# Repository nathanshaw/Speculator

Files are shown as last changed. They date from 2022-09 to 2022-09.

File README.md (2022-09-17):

# Speculator Hardware

This repo contains the PCB layout and schematic files for the Speculator genus.
Speculator is one of three genera developed for the Acropolis family of soundscape augmentation artefacts. Speculator specialises in non-cochlear soundscape augmentation.

The files were created within EAGLE CAD

The Speculator genus firmware is contained in this repo: https://github.com/nathanshaw/unified_hss_firmware

More information about this project can be found here: https://nathanvillicanashaw.com/archive
The Explorator genus can be found here: https://github.com/nathanshaw/explorator
The Legatus genus can be found here: https://github.com/nathanshaw/legatus

The following PCB designs are included in this repo:
----------------------------------------------------

### Speculator major (large)
    96mm diameter
    1x Teensy 3.2 Microcontroller
    1x power switch
    6x firmware control switches
    10x WS2813 NeoPixel LEDs
    2x VEML 6030 Ambient Light Sensors
    2x onboard 18650 LiPo Batteries
    1x 5v voltage regulator (TODO): https://www.pololu.com/product/2870

### Speculator minor mainboard (small)
    76mm diameter
    1x Teensy 3.2 Microcontroller
    1x power switch
    10x firmware control switches
    4x firmware control potentiometers 
    20x WS2813 NeoPixel LEDs
    1x SHTC3 Temperature and Humidity Sensor
    2x onboard 18500 LiPo Batteries
    1x 5v voltage regulator (TODO): https://www.pololu.com/product/2870

### Speculator minor breakout PCB
    54mm diameter
    10-pin JST connector to mate with mainboard
    1x VEML 6030 Ambient Light Sensors
    1x TDK ICS-43434 MEMs microphone
    10x WS2813 NeoPixel LEDs

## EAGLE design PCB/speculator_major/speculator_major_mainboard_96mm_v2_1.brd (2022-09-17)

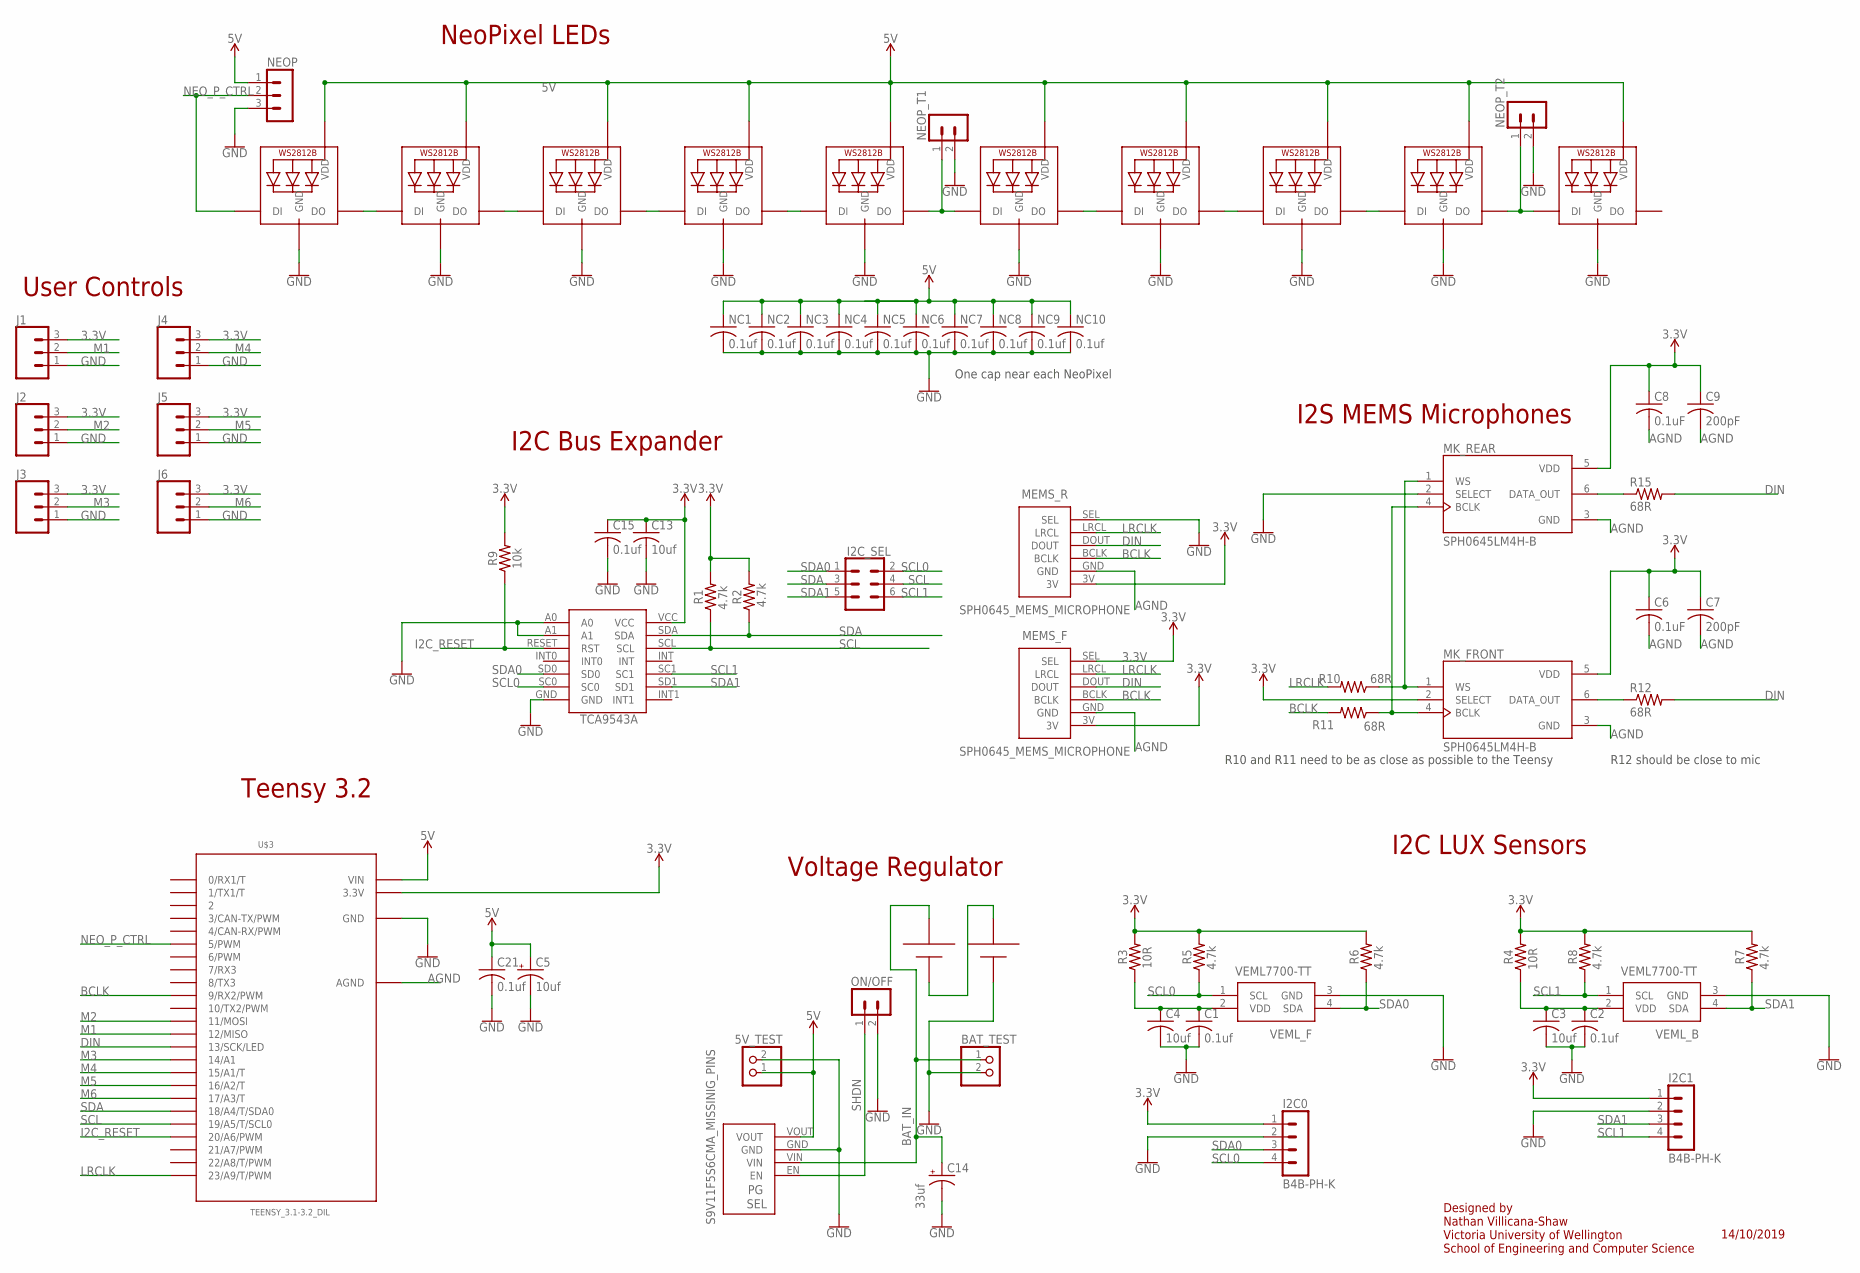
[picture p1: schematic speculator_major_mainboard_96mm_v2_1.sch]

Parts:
5V_TEST: PINHD-1X2; 1X02
BAT_TEST: PINHD-1X2; 1X02
C1, C2, C15, C21: 0.1uf; C1206K
C3, C4, C13: 10uf; C1206K
C5: 10uf; E2,5-6
C6, C8: 0.1uF; C1206K
C7, C9: 200pF; C1206K
C14: 33uf; E2-5
I2C0, I2C1: B4B-PH-K
I2C_SEL: FEMALE 2x3; 2X3
J1, J2, J3, J4, J5, J6: CONN_03; 1X03
MEMS_F: SPH0645_MEMS_MICROPHONE; SPH0645
MEMS_R: SPH0645_MEMS_MICROPHONE; SPH0645
MK_FRONT: SPH0645LM4H-B; MIC_SPH0645LM4H-B
MK_REAR: SPH0645LM4H-B; MIC_SPH0645LM4H-B
NC1, NC2, NC3, NC4, NC5, NC6, NC7, NC8, NC9, NC10: 0.1uf; C1206K
NEO1, NEO2, NEO3, NEO4, NEO5, NEO6, NEO7, NEO8, NEO9, NEO10: WS2812B5050; WS2812B
NEOP: B3B-PH-K
NEOP_T1, NEOP_T2: B2B-PH-K
ON/OFF: B2B-PH-K
R1, R2, R5, R6, R7, R8: 4.7k; R1206W
R3, R4: 10R; R1206W
R9: 10k; R1206W
R10, R11, R12, R15: 68R; M1206
U$1: TCA9543A; SO14
U$2: BK-18650-PC4; 18650-PC4
U$3: TEENSY_3.1-3.2_DIL; TEENSY_3.0-3.2&LC_DIL
U$6: S9V11F5S6CMA_MISSINIG_PINS; S9V11F3S5CMA_MISSING_PINS
VEML_B: VEML7700-TT; VEML7700
VEML_F: VEML7700-TT; VEML7700

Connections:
3.3V: C6.1, C7.1, C8.1, C9.1, C13.1, C15.1, I2C0.1, I2C1.1, J1.3, J2.3, J3.3, J4.3, J5.3, J6.3, MEMS_F.3V, MEMS_F.SEL, MEMS_R.3V, MK_FRONT.2 (SELECT), MK_FRONT.5 (VDD), MK_REAR.5 (VDD), R1.2, R2.2, R3.2, R4.2, R5.2, R6.2, R7.2, R8.2, R9.2, U$1.VCC, U$3.3.3V
5V: 5V_TEST.1, C5.+, C21.1, NC1.1, NC2.1, NC3.1, NC4.1, NC5.1, NC6.1, NC7.1, NC8.1, NC9.1, NC10.1, NEO1.1-VDD (VDD), NEO2.1-VDD (VDD), NEO3.1-VDD (VDD), NEO4.1-VDD (VDD), NEO5.1-VDD (VDD), NEO6.1-VDD (VDD), NEO7.1-VDD (VDD), NEO8.1-VDD (VDD), NEO9.1-VDD (VDD), NEO10.1-VDD (VDD), NEOP.1, U$3.VIN, U$6.VOUT
AGND: C6.2, C7.2, C8.2, C9.2, MEMS_F.GND, MEMS_R.GND, MK_FRONT.3 (GND), MK_REAR.3 (GND), U$3.AGND
BAT_IN: BAT_TEST.1, C14.+, U$2.+1, U$6.VIN
BCLK: MEMS_F.BCLK, MEMS_R.BCLK, R11.2, U$3.9 (9/RX2/PWM)
BCLK_P: MK_FRONT.4 (BCLK), MK_REAR.4 (BCLK), R11.1
DIN: MEMS_F.DOUT, MEMS_R.DOUT, R12.2, R15.2, U$3.13 (13/SCK/LED)
GND: 5V_TEST.2, BAT_TEST.2, C1.2, C2.2, C3.2, C4.2, C5.-, C13.2, C14.-, C15.2, C21.2, I2C0.2, I2C1.2, J1.1, J2.1, J3.1, J4.1, J5.1, J6.1, MEMS_R.SEL, MK_REAR.2 (SELECT), NC1.2, NC2.2, NC3.2, NC4.2, NC5.2, NC6.2, NC7.2, NC8.2, NC9.2, NC10.2, NEO1.3-GND (GND), NEO2.3-GND (GND), NEO3.3-GND (GND), NEO4.3-GND (GND), NEO5.3-GND (GND), NEO6.3-GND (GND), NEO7.3-GND (GND), NEO8.3-GND (GND), NEO9.3-GND (GND), NEO10.3-GND (GND), NEOP.3, NEOP_T1.2, NEOP_T2.2, ON/OFF.2, U$1.A0, U$1.A1, U$1.GND, U$2.-2, U$3.GND, U$6.GND, VEML_B.3 (GND), VEML_F.3 (GND)
I2C_RESET: R9.1, U$1.RESET (RST), U$3.20/A6 (20/A6/PWM)
LRCLK: MEMS_F.LRCL, MEMS_R.LRCL, R10.2, U$3.23/A9 (23/A9/T/PWM)
LRCLK_P: MK_FRONT.1 (WS), MK_REAR.1 (WS), R10.1
M1: J1.2, U$3.12 (12/MISO)
M2: J2.2, U$3.11 (11/MOSI)
M3: J3.2, U$3.14/A0 (14/A1)
M4: J4.2, U$3.15/A1 (15/A1/T)
M5: J5.2, U$3.16/A2 (16/A2/T)
M6: J6.2, U$3.17/A3 (17/A3/T)
unnamed: C1.1, C4.1, R3.1, VEML_F.2 (VDD)
unnamed: C2.1, C3.1, R4.1, VEML_B.2 (VDD)
unnamed: MK_FRONT.6 (DATA_OUT), R12.1
unnamed: NEO2.2-DOUT (DO), NEO3.4-DIN (DI)
unnamed: NEO5.2-DOUT (DO), NEO6.4-DIN (DI), NEOP_T1.1
unnamed: NEO9.2-DOUT (DO), NEO10.4-DIN (DI), NEOP_T2.1
unnamed: NEO4.2-DOUT (DO), NEO5.4-DIN (DI)
unnamed: NEO3.2-DOUT (DO), NEO4.4-DIN (DI)
unnamed: NEO7.2-DOUT (DO), NEO8.4-DIN (DI)
unnamed: NEO8.2-DOUT (DO), NEO9.4-DIN (DI)
unnamed: MK_REAR.6 (DATA_OUT), R15.1
unnamed: U$2.+2, U$2.-1
unnamed: NEO6.2-DOUT (DO), NEO7.4-DIN (DI)
NEO_P1: NEO1.2-DOUT (DO), NEO2.4-DIN (DI)
NEO_P_CTRL: NEO1.4-DIN (DI), NEOP.2, U$3.5 (5/PWM)
SCL: I2C_SEL.4, R1.1, U$1.SCL, U$3.19/A5 (19/A5/T/SCL0)
SCL0: I2C0.4, I2C_SEL.2, R5.1, U$1.SC0, VEML_F.1 (SCL)
SCL1: I2C1.4, I2C_SEL.6, R8.1, U$1.SC1, VEML_B.1 (SCL)
SDA: I2C_SEL.3, R2.1, U$1.SDA, U$3.18/A4 (18/A4/T/SDA0)
SDA0: I2C0.3, I2C_SEL.1, R6.1, U$1.SD0, VEML_F.4 (SDA)
SDA1: I2C1.3, I2C_SEL.5, R7.1, U$1.SD1, VEML_B.4 (SDA)
SHDN: ON/OFF.1, U$6.EN

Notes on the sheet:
I2S MEMS Microphones
Voltage Regulator
I2C LUX Sensors
I2C Bus Expander
NeoPixel LEDs
10k
4.7k
One cap near each NeoPixel
R10 and R11 need to be as close as possible to the Teensy
R12 should be close to mic
10R
Teensy 3.2
Designed by Nathan Villicana-Shaw Victoria University of Wellington School of Engineering and Computer Science
14/10/2019
User Controls

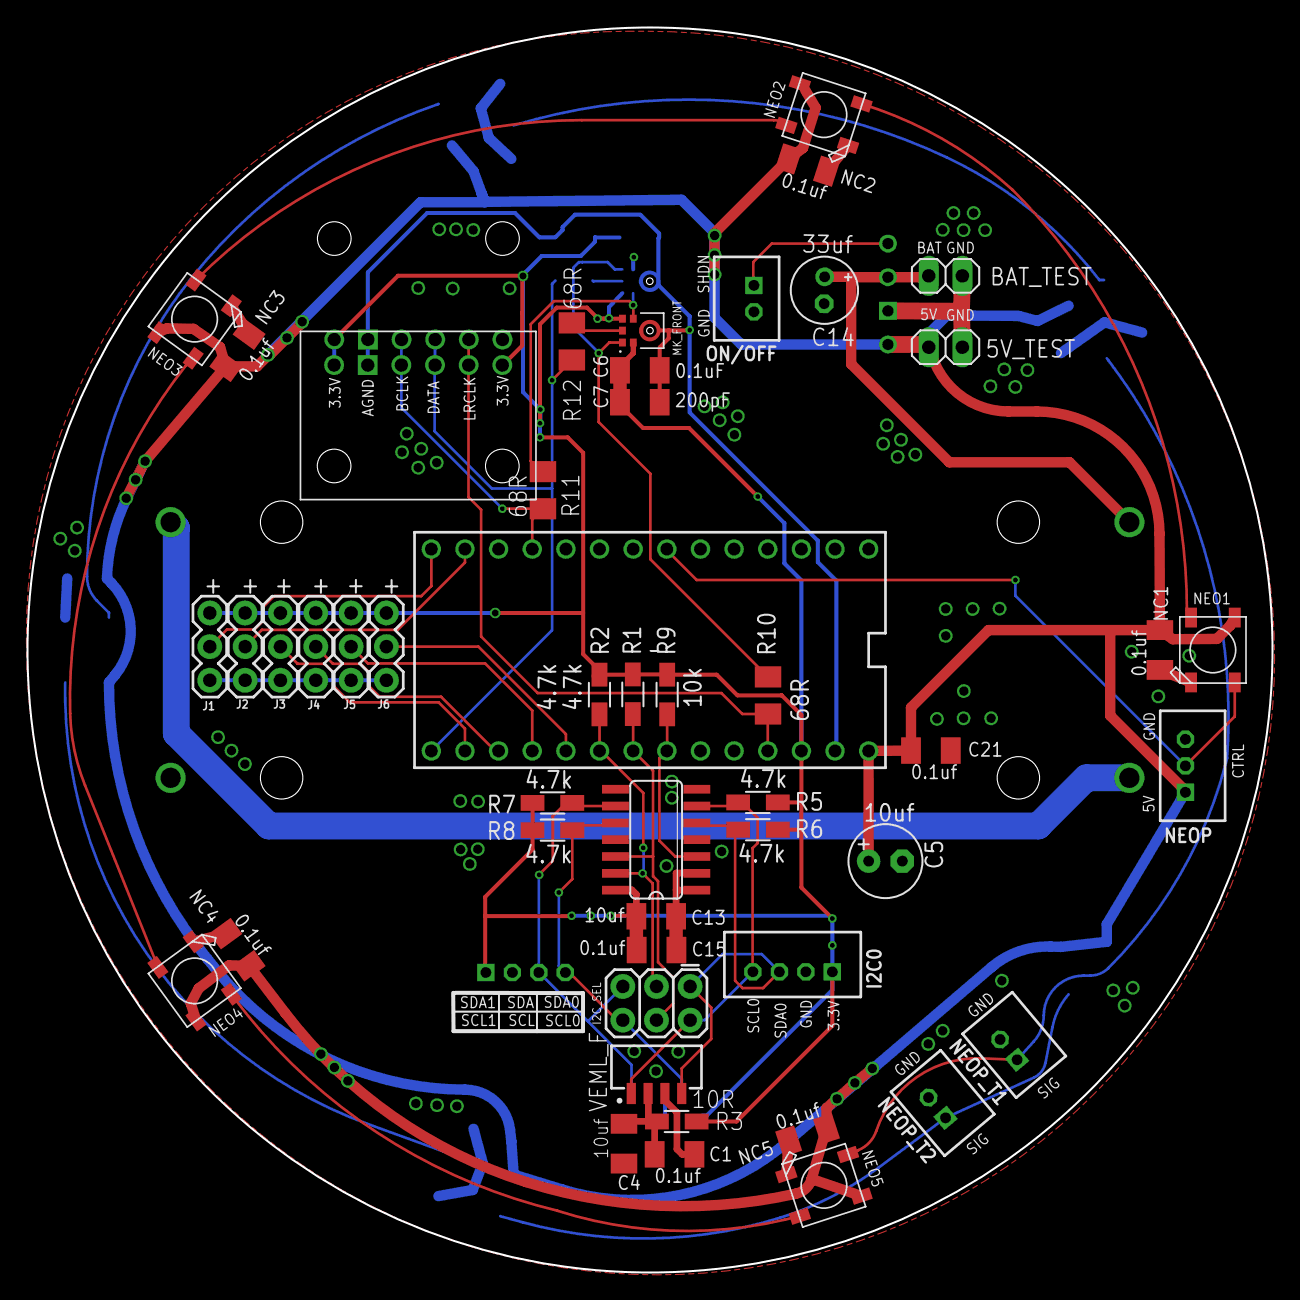
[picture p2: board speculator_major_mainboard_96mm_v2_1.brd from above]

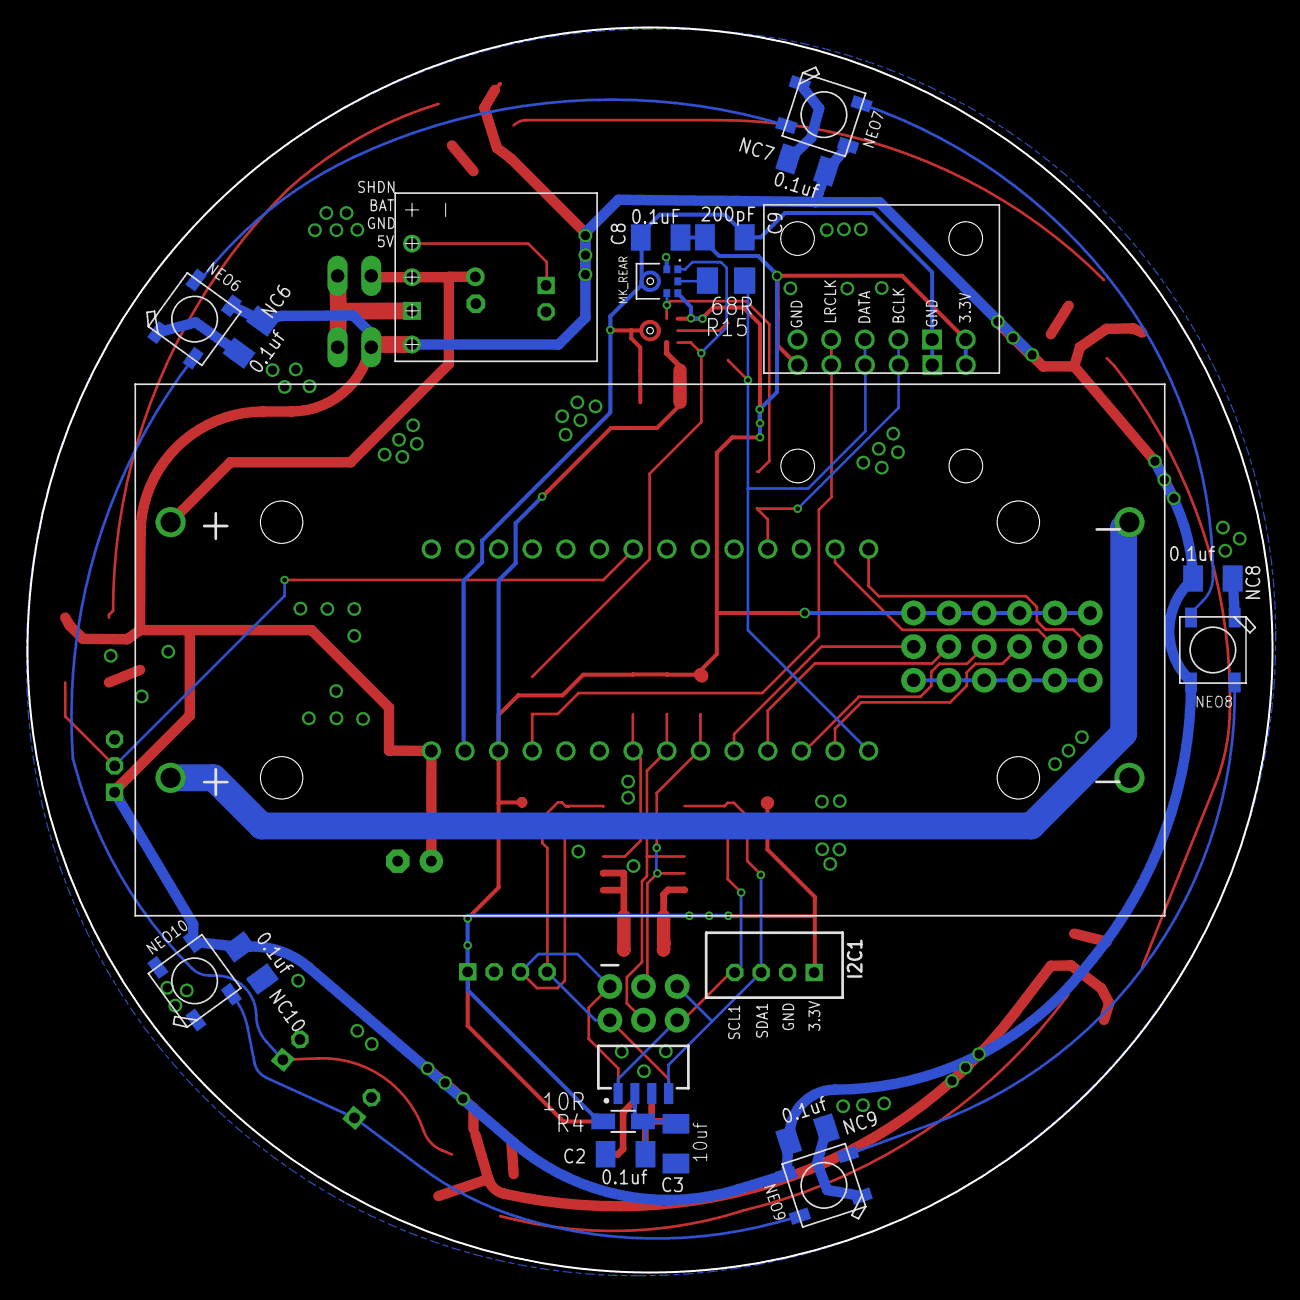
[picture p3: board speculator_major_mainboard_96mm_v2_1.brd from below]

Board: 2 copper layers, 94.0 x 94.0 mm, 71 parts (22 on the bottom side), 39 nets.

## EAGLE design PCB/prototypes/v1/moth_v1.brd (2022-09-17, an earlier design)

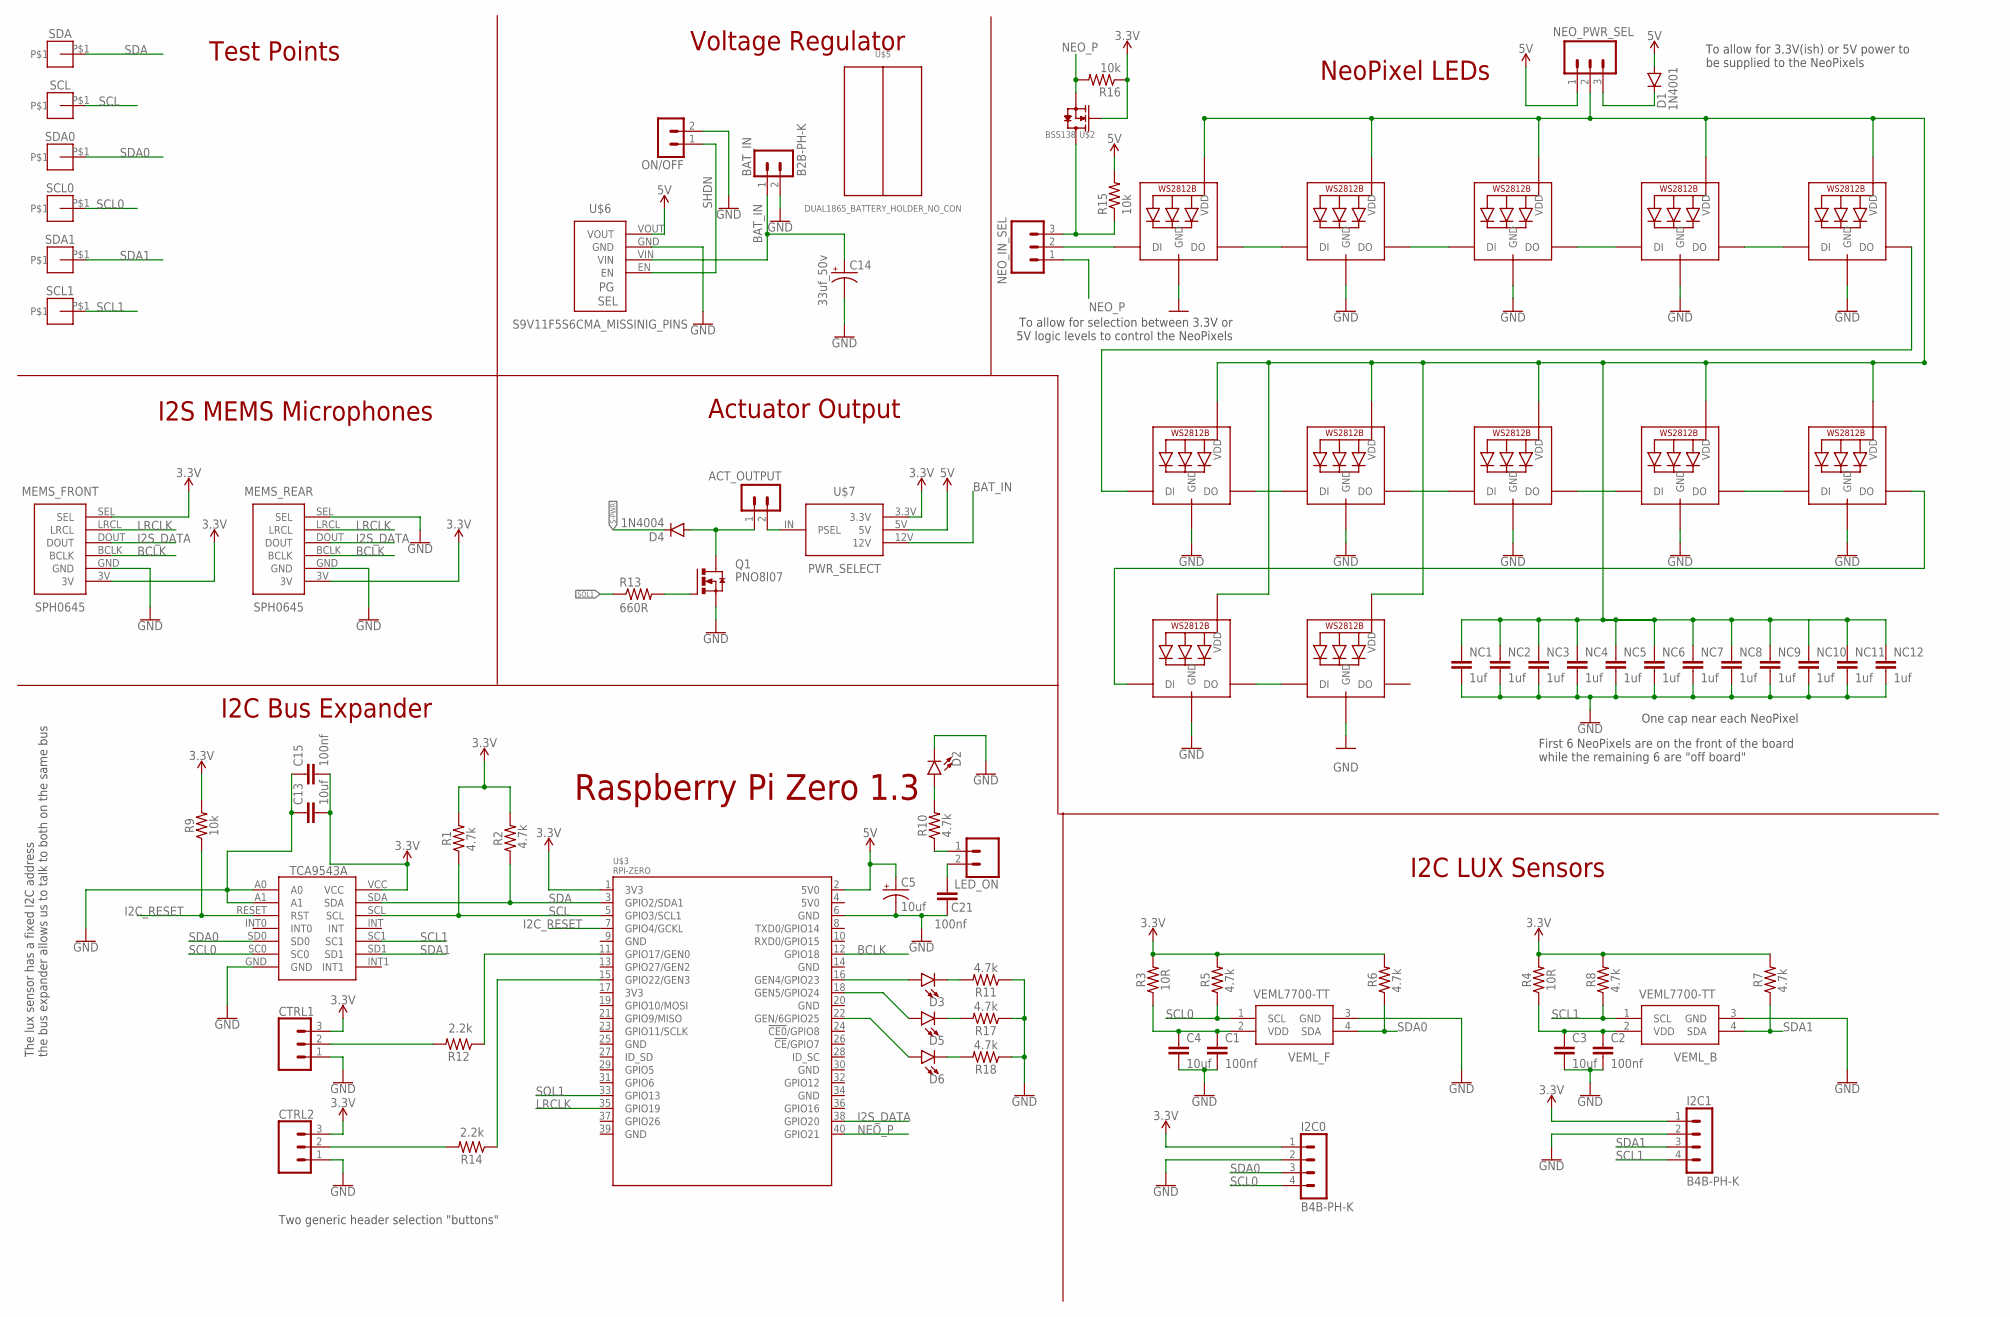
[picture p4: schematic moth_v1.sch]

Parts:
ACT_OUTPUT: B2B-PH-K
BAT_IN: B2B-PH-K
C1, C2, C15, C21: 100nf; 0603
C3, C4, C13: 10uf; 0603
C5: 10uf; E2,5-6
C14: 33uf_50v; E2-5
CTRL1, CTRL2: CONN_03; 1X03
D1: 1N4001; DIODE-1N4001
D2, D3, D5, D6: LED-FKIT-1206; FKIT-LED-1206
D4: 1N4004; DIODE-1N4001
I2C0, I2C1: B4B-PH-K
LED_ON: CONN_021X02_NO_SILK; 1X02_NO_SILK
MEMS_FRONT: SPH0645
MEMS_REAR: SPH0645
NC1, NC2, NC3, NC4, NC5, NC6, NC7, NC8, NC9, NC10, NC11, NC12: 1uf; 0603
NEO_01, NEO_02, NEO_03, NEO_04, NEO_05, NEO_06, NEO_07, NEO_08, NEO_09, NEO_10, NEO_11, NEO_12: WS2812B_5050N; WS2812B-NARROW
NEO_IN_SEL: CONN_03; 1X03
NEO_PWR_SEL: CONN_03; 1X03
ON/OFF: B2B-PH-K
Q1: PNO8l07; TO220BH
R1, R2, R5, R6, R7, R8: 4.7k; 0207/10
R3, R4: 10R; 0603
R9: 10k; 0207/10
R10, R11, R17, R18: 4.7k; 0603
R12, R14: 2k; 0207/10
R13: 660R; 0207/10
R15, R16: 10k; 0603
SCL, SCL0, SCL1: TEST_POINT_LARGE
SDA, SDA0, SDA1: TEST_POINT_LARGE
U$1: TCA9543A; SO14
U$2: BSS138; SOT23-3
U$3: RPI-ZERO; RASPBERRYPI_BASTELSTUBE_V13_RASPI_BOARD_B+_FULL
U$5: DUAL1865_BATTERY_HOLDER_NO_CON; DUAL_18650_BAT_HOLDER_NO_CON
U$6: S9V11F5S6CMA_MISSINIG_PINS; S9V11F3S5CMA_MISSING_PINS
U$7: PWR_SELECT; PWR_SELECT_PINOUT
VEML_B: VEML7700-TT; VEML7700
VEML_F: VEML7700-TT; VEML7700

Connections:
3.3V: C13.2, C15.2, CTRL1.3, CTRL2.3, I2C0.1, I2C1.1, MEMS_FRONT.3V, MEMS_FRONT.SEL, MEMS_REAR.3V, R1.2, R2.2, R3.2, R4.2, R5.2, R6.2, R7.2, R8.2, R9.2, R16.1, U$1.VCC, U$2.1 (G), U$3.1 (3V3), U$7.3.3V
5V: C5.+, D1.A, NEO_PWR_SEL.1, R15.2, U$3.2 (5V0), U$6.VOUT, U$7.5V
BAT_IN: BAT_IN.1, C14.+, U$6.VIN, U$7.12V
BCLK: MEMS_FRONT.BCLK, MEMS_REAR.BCLK, U$3.12 (GPIO18)
GND: BAT_IN.2, C1.2, C2.2, C3.2, C4.2, C5.-, C13.1, C14.-, C15.1, C21.1, CTRL1.1, CTRL2.1, D2.C, I2C0.2, I2C1.2, MEMS_FRONT.GND, MEMS_REAR.GND, MEMS_REAR.SEL, NC1.2, NC2.2, NC3.2, NC4.2, NC5.2, NC6.2, NC7.2, NC8.2, NC9.2, NC10.2, NC11.2, NC12.2, NEO_01.3-GND (GND), NEO_02.3-GND (GND), NEO_03.3-GND (GND), NEO_04.3-GND (GND), NEO_05.3-GND (GND), NEO_06.3-GND (GND), NEO_07.3-GND (GND), NEO_08.3-GND (GND), NEO_09.3-GND (GND), NEO_10.3-GND (GND), NEO_11.3-GND (GND), NEO_12.3-GND (GND), ON/OFF.2, Q1.S, R11.1, R17.1, R18.1, U$1.A0, U$1.A1, U$1.GND, U$3.6 (GND), U$6.GND, VEML_B.3 (GND), VEML_F.3 (GND)
I2C_RESET: R9.1, U$1.RESET (RST), U$3.7 (GPIO4/GCKL)
I2S_DATA: MEMS_FRONT.DOUT, MEMS_REAR.DOUT, U$3.38 (GPIO20)
LRCLK: MEMS_FRONT.LRCL, MEMS_REAR.LRCL, U$3.35 (GPIO19)
unnamed: C1.1, C4.1, R3.1, VEML_F.2 (VDD)
unnamed: C2.1, C3.1, R4.1, VEML_B.2 (VDD)
unnamed: R12.1, U$3.11 (GPIO17/GEN0)
unnamed: NEO_02.2-DOUT (DO), NEO_03.4-DIN (DI)
unnamed: NEO_05.2-DOUT (DO), NEO_06.4-DIN (DI)
unnamed: NEO_11.2-DOUT (DO), NEO_12.4-DIN (DI)
unnamed: NEO_04.2-DOUT (DO), NEO_05.4-DIN (DI)
unnamed: NC1.1, NC2.1, NC3.1, NC4.1, NC5.1, NC6.1, NC7.1, NC8.1, NC9.1, NC10.1, NC11.1, NC12.1, NEO_01.1-VDD (VDD), NEO_02.1-VDD (VDD), NEO_03.1-VDD (VDD), NEO_04.1-VDD (VDD), NEO_05.1-VDD (VDD), NEO_06.1-VDD (VDD), NEO_07.1-VDD (VDD), NEO_08.1-VDD (VDD), NEO_09.1-VDD (VDD), NEO_10.1-VDD (VDD), NEO_11.1-VDD (VDD), NEO_12.1-VDD (VDD), NEO_PWR_SEL.2
unnamed: NEO_03.2-DOUT (DO), NEO_04.4-DIN (DI)
unnamed: NEO_07.2-DOUT (DO), NEO_08.4-DIN (DI)
unnamed: NEO_08.2-DOUT (DO), NEO_09.4-DIN (DI)
unnamed: NEO_09.2-DOUT (DO), NEO_10.4-DIN (DI)
unnamed: NEO_10.2-DOUT (DO), NEO_11.4-DIN (DI)
unnamed: R14.1, U$3.15 (GPIO22/GEN3)
unnamed: D2.A, R10.2
unnamed: CTRL2.2, R14.2
unnamed: CTRL1.2, R12.2
unnamed: Q1.G, R13.2
unnamed: ACT_OUTPUT.1, D4.A, Q1.D
unnamed: NEO_06.2-DOUT (DO), NEO_07.4-DIN (DI)
unnamed: C21.2, LED_ON.2
unnamed: D1.C, NEO_PWR_SEL.3
unnamed: NEO_IN_SEL.3, R15.1, U$2.3 (D)
unnamed: LED_ON.1, R10.1
unnamed: D3.C, R11.2
unnamed: D5.C, R17.2
unnamed: D6.C, R18.2
unnamed: D3.A, U$3.16 (GEN4/GPIO23)
unnamed: D5.A, U$3.18 (GEN5/GPIO24)
unnamed: D6.A, U$3.22 (GEN/6GPIO25)
NEO_P: NEO_IN_SEL.1, R16.2, U$2.2 (S), U$3.40 (GPIO21)
NEO_P1: NEO_01.2-DOUT (DO), NEO_02.4-DIN (DI)
NEO_P99: NEO_01.4-DIN (DI), NEO_IN_SEL.2
S-PWR: ACT_OUTPUT.2, D4.C, U$7.IN (PSEL)
SCL: R1.1, SCL.P$1, U$1.SCL, U$3.5 (GPIO3/SCL1)
SCL0: I2C0.4, R5.1, SCL0.P$1, U$1.SC0, VEML_F.1 (SCL)
SCL1: I2C1.4, R8.1, SCL1.P$1, U$1.SC1, VEML_B.1 (SCL)
SDA: R2.1, SDA.P$1, U$1.SDA, U$3.3 (GPIO2/SDA1)
SDA0: I2C0.3, R6.1, SDA0.P$1, U$1.SD0, VEML_F.4 (SDA)
SDA1: I2C1.3, R7.1, SDA1.P$1, U$1.SD1, VEML_B.4 (SDA)
SHDN: ON/OFF.1, U$6.EN
SOL1: R13.1, U$3.33 (GPIO13)

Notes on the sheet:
I2S MEMS Microphones
Voltage Regulator
Actuator Output
Raspberry Pi Zero 1.3
I2C LUX Sensors
I2C Bus Expander
NeoPixel LEDs
10k
4.7k
2.2k
660R
One cap near each NeoPixel
To allow for 3.3V(ish) or 5V power to be supplied to the NeoPixels
To allow for selection between 3.3V or 5V logic levels to control the NeoPixels
First 6 NeoPixels are on the front of the board while the remaining 6 are "off board"
Two generic header selection "buttons"
The lux sensor has a fixed I2C address the bus expander allows us to talk to both on the same bus
Test Points

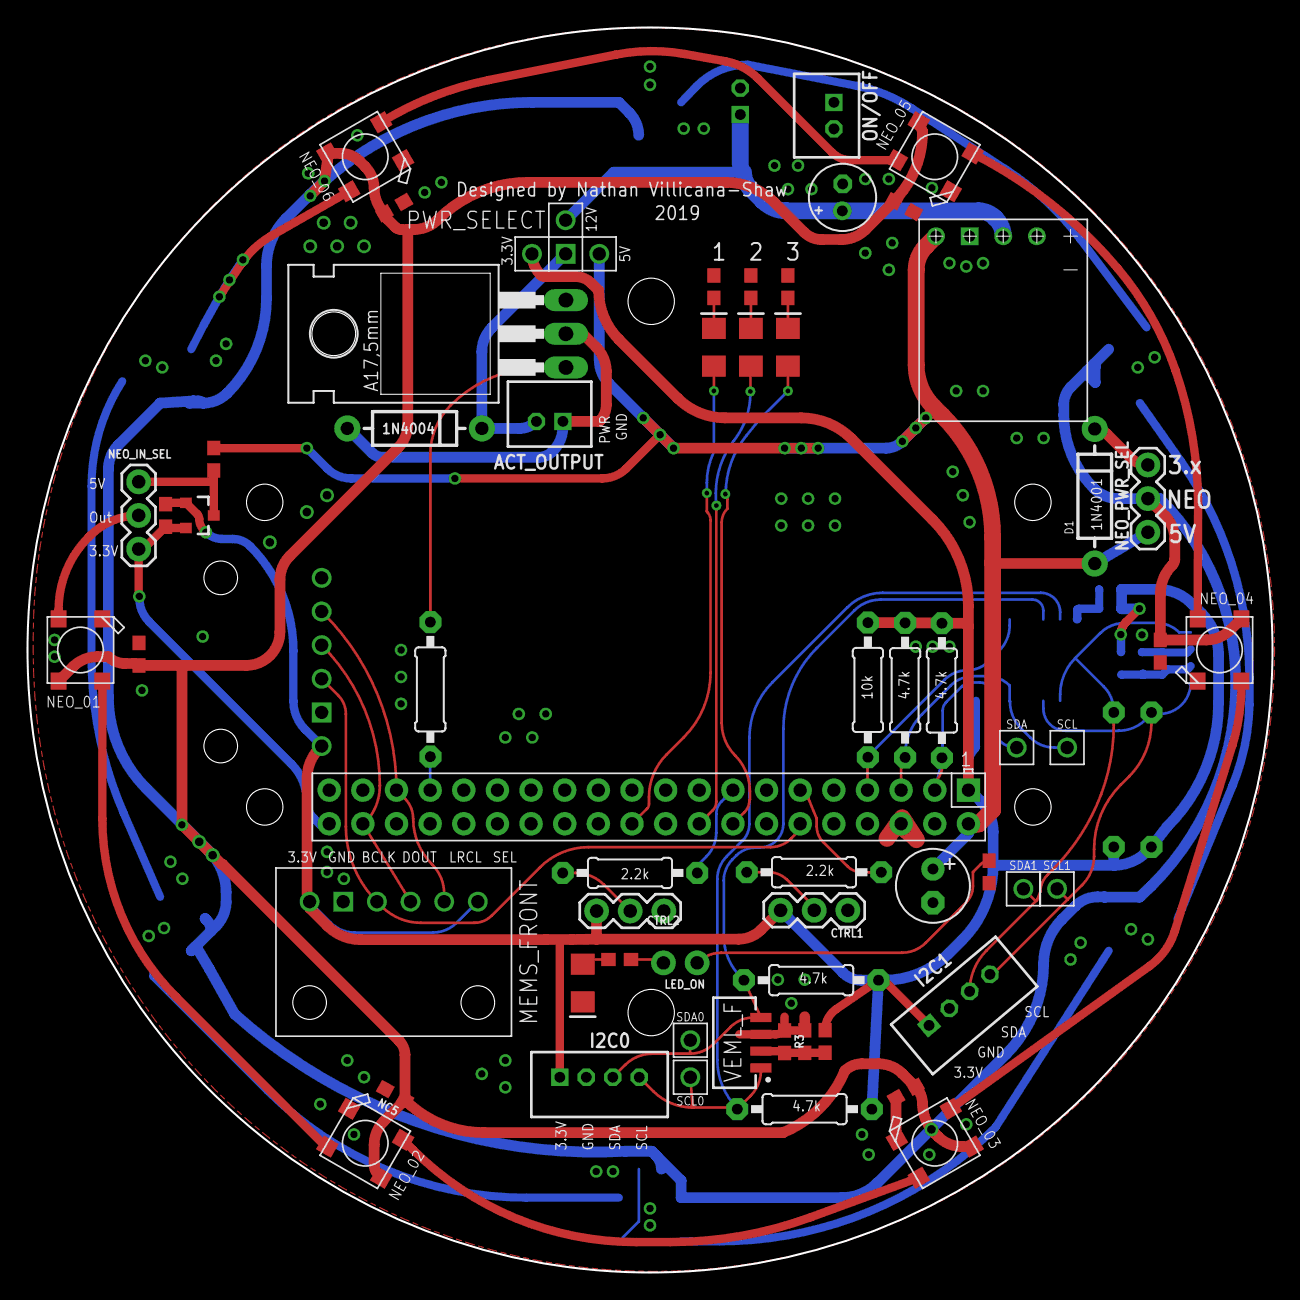
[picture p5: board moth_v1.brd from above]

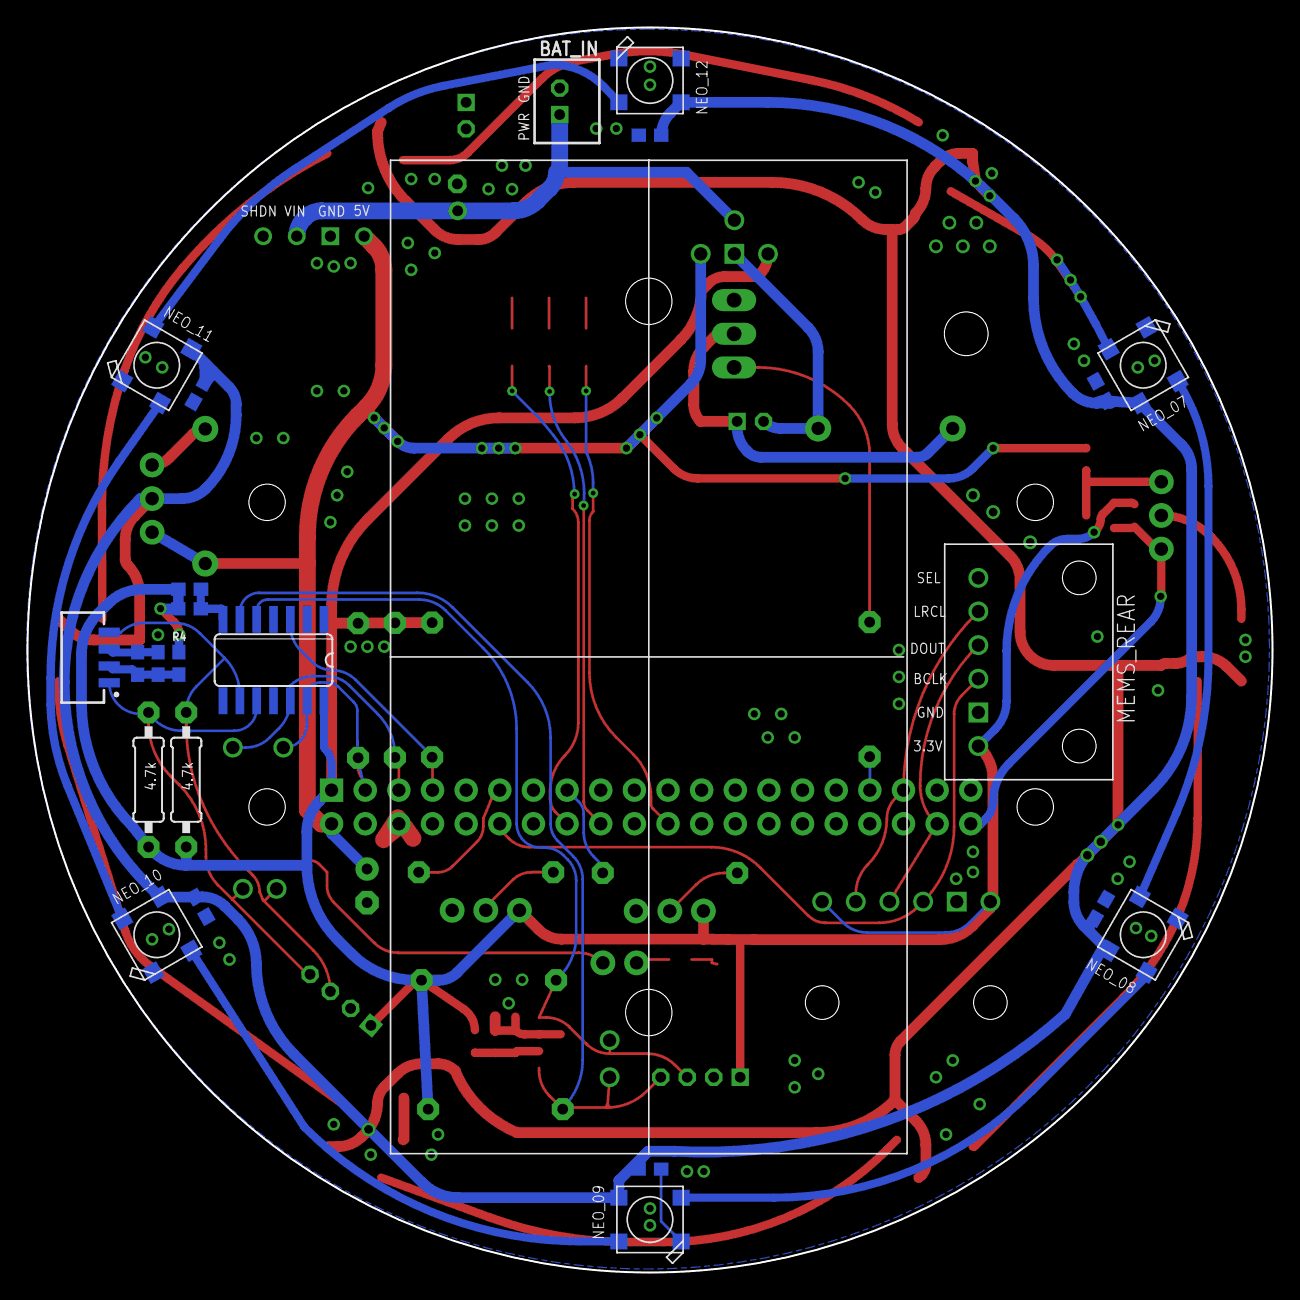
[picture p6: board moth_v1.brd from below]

Board: 2 copper layers, 94.0 x 94.0 mm, 84 parts (24 on the bottom side), 50 nets.

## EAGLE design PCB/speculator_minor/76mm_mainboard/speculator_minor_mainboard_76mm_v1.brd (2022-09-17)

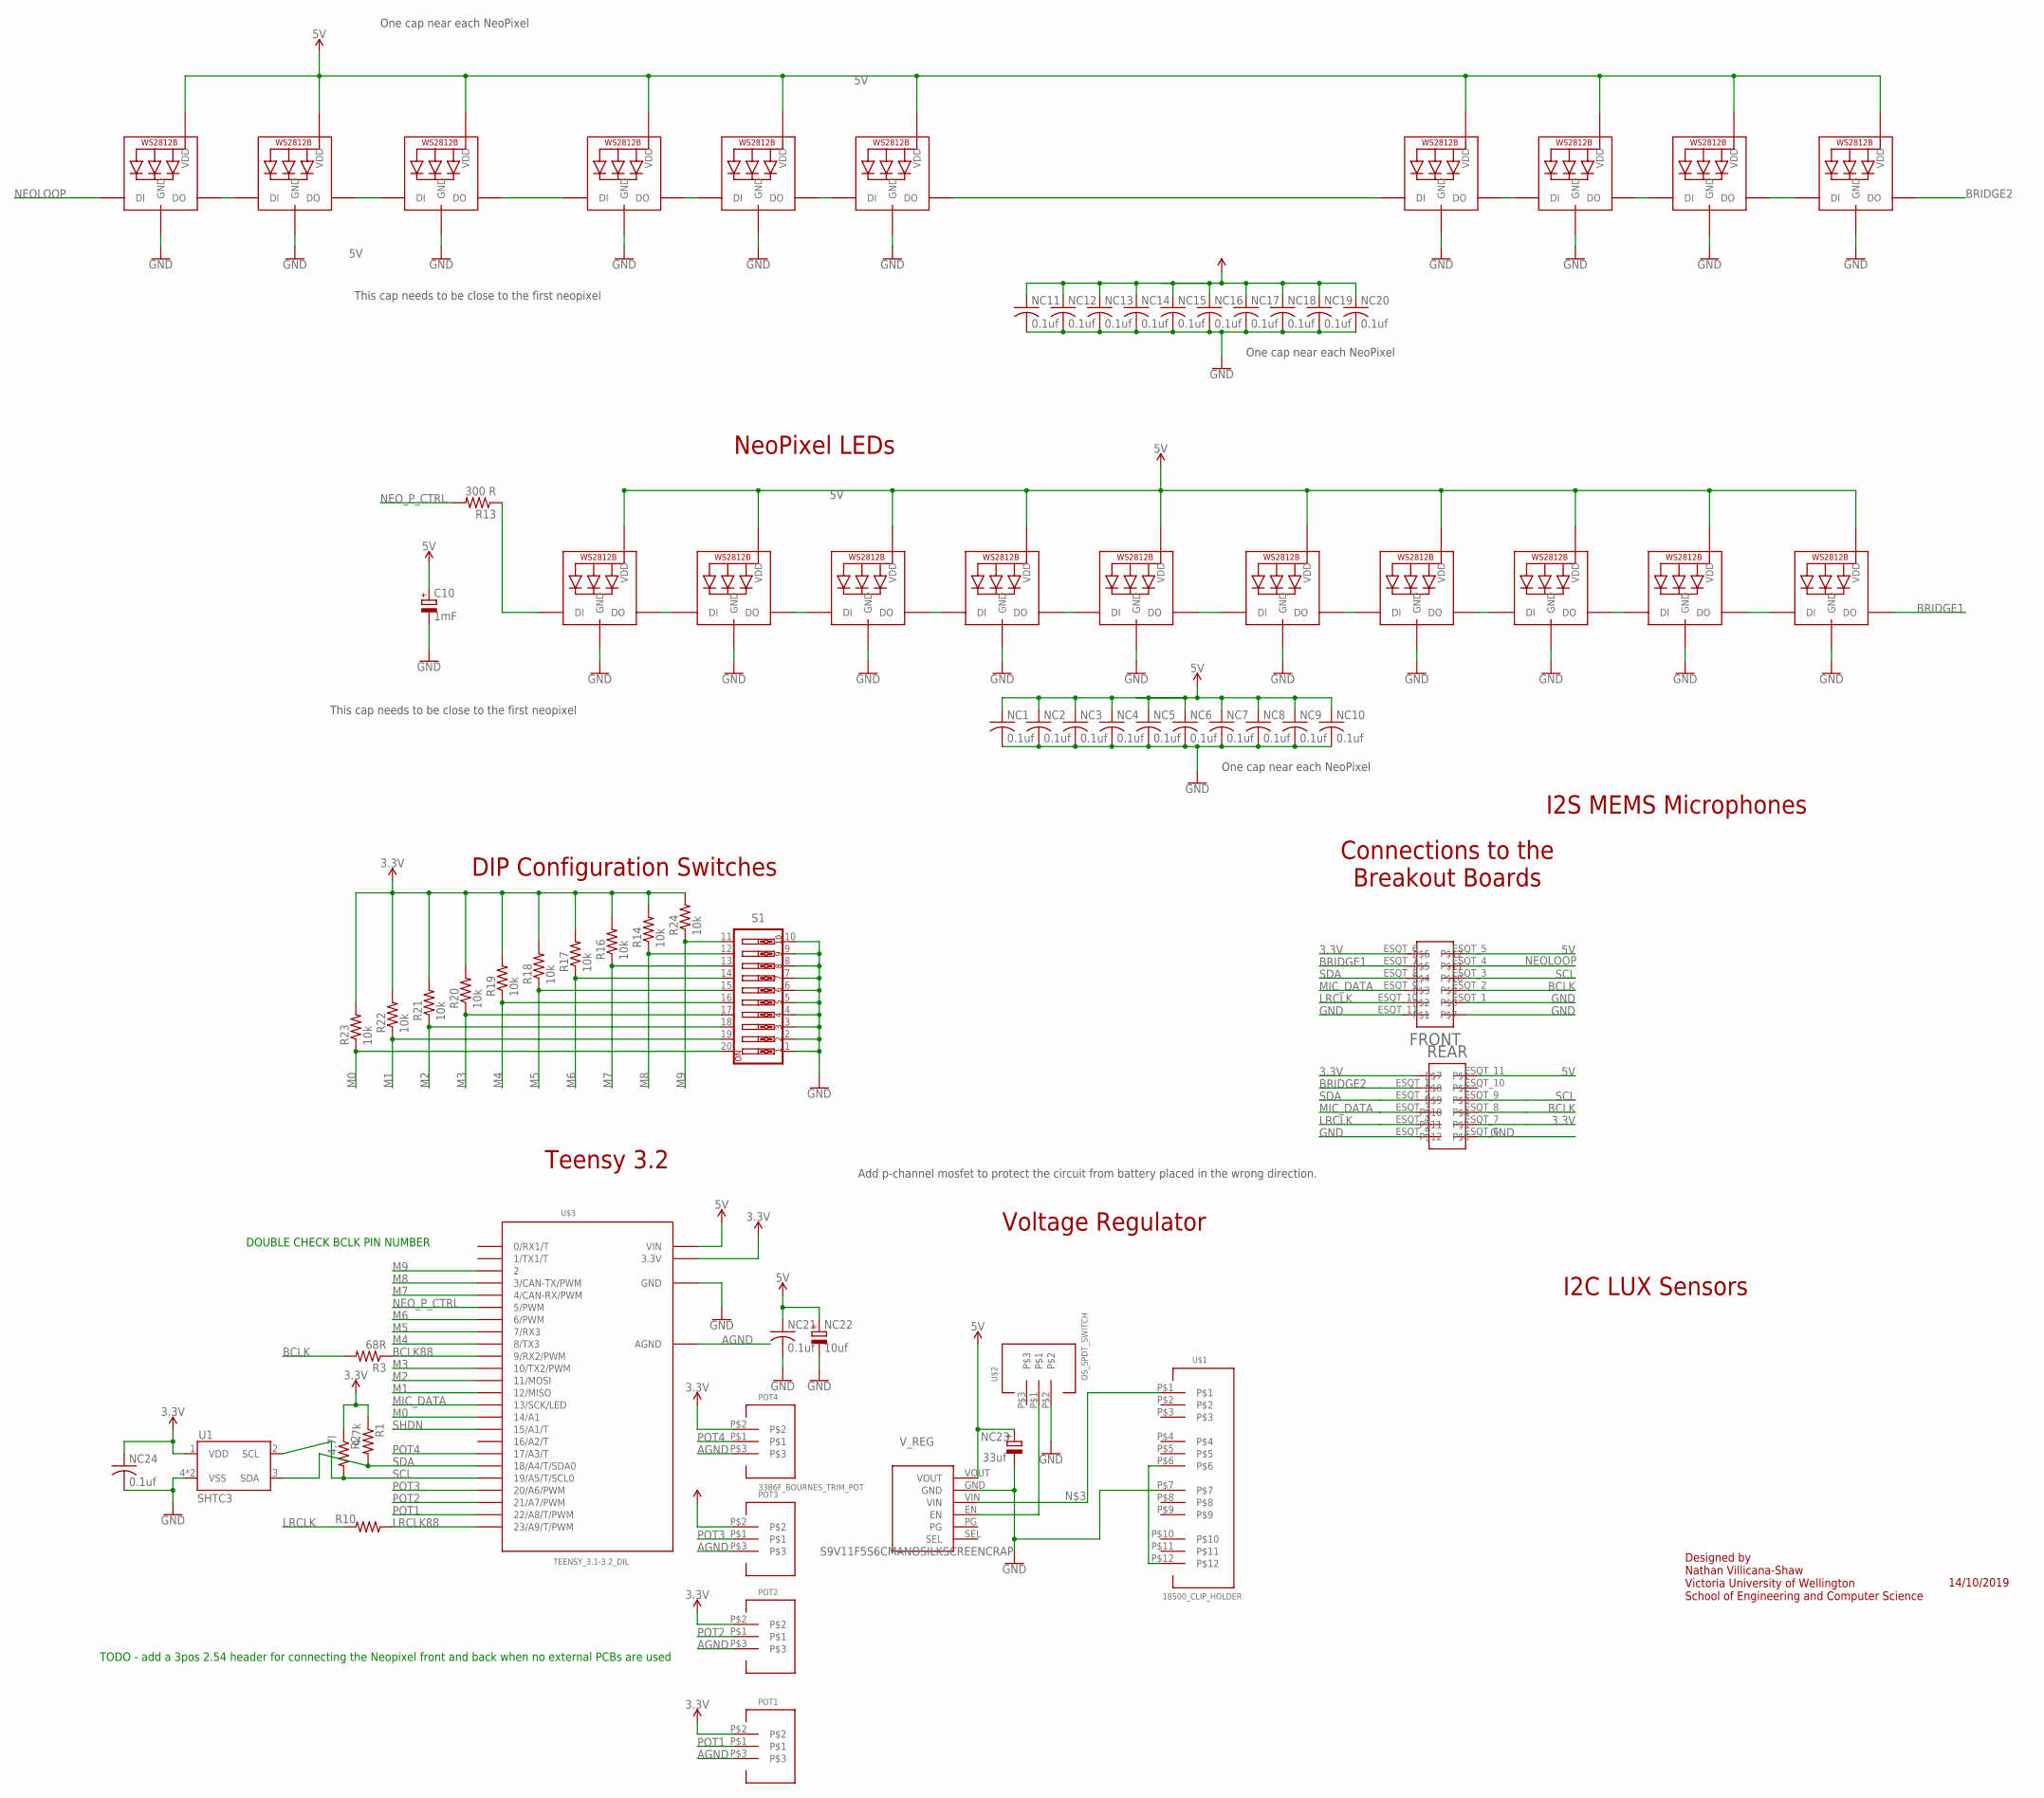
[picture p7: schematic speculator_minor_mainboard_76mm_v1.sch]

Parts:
C10: 1mF; 153CLV-1010
FRONT: SAMTEC_ESQT_2X6_THROUGH_HOLE
NC1, NC2, NC3, NC4, NC5, NC6, NC7, NC8, NC9, NC10, NC11, NC12, NC13, NC14, NC15, NC16, NC17, NC18, NC19, NC20, NC21, NC24: 0.1uf; C0805K
NC22: 10uf; E2,5-7
NC23: 33uf; E2,5-7
NEO1, NEO2, NEO3, NEO4, NEO5, NEO6, NEO7, NEO8, NEO9, NEO10, NEO11, NEO12, NEO13, NEO14, NEO15, NEO16, NEO17, NEO18, NEO19, NEO20: WS2812B5050; WS2812B
POT1, POT2, POT3, POT4: 3386F_BOURNES_TRIM_POT; 3386_BOURNS_TRIM_POT
R1: 4.7k; R0805
R2: 4.7l; R0805
R3, R10: 68R; R0805
R13: 300 R; R0805
R14, R16, R17, R18, R19, R20, R21, R22, R24: 10k; R0805
R23: 10k; M0805
REAR: SAMTEC_ESQT_2X6_THROUGH_HOLE
S1: SW_DIP-10; EDG-10
U1: SHTC3
U$1: 18500_CLIP_HOLDER; 3PINBATTERY_CLIP
U$2: OS_SPDT_SWITCH; OS_SPDT_SLIDE_SWITCH
U$3: TEENSY_3.1-3.2_DIL; TEENSY_3.0-3.2&LC_DIL
V_REG: S9V11F5S6CMANOSILKSCREENCRAP; S9V11F3S5CMA_BETTER_PINS

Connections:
3.3V: FRONT.ESQT_6, NC24.1, POT1.P$2, POT2.P$2, POT3.P$2, POT4.P$2, R1.1, R2.1, R14.2, R16.2, R17.2, R18.2, R19.2, R20.2, R21.2, R22.2, R23.2, R24.2, REAR.ESQT_0, REAR.ESQT_7, U1.1 (VDD), U$3.3.3V
5V: C10.+, FRONT.ESQT_5, NC1.1, NC2.1, NC3.1, NC4.1, NC5.1, NC6.1, NC7.1, NC8.1, NC9.1, NC10.1, NC11.1, NC12.1, NC13.1, NC14.1, NC15.1, NC16.1, NC17.1, NC18.1, NC19.1, NC20.1, NC21.1, NC22.+, NC23.+, NEO1.1-VDD (VDD), NEO2.1-VDD (VDD), NEO3.1-VDD (VDD), NEO4.1-VDD (VDD), NEO5.1-VDD (VDD), NEO6.1-VDD (VDD), NEO7.1-VDD (VDD), NEO8.1-VDD (VDD), NEO9.1-VDD (VDD), NEO10.1-VDD (VDD), NEO11.1-VDD (VDD), NEO12.1-VDD (VDD), NEO13.1-VDD (VDD), NEO14.1-VDD (VDD), NEO15.1-VDD (VDD), NEO16.1-VDD (VDD), NEO17.1-VDD (VDD), NEO18.1-VDD (VDD), NEO19.1-VDD (VDD), NEO20.1-VDD (VDD), REAR.ESQT_11, U$3.VIN, V_REG.VOUT
AGND: POT1.P$3, POT2.P$3, POT3.P$3, POT4.P$3, U$3.AGND
BCLK: FRONT.ESQT_2, R3.2, REAR.ESQT_8
BCLK88: R3.1, U$3.9 (9/RX2/PWM)
BRIDGE1: FRONT.ESQT_7, NEO10.2-DOUT (DO)
BRIDGE2: NEO20.2-DOUT (DO), REAR.ESQT_1
GND: C10.-, FRONT.ESQT_0, FRONT.ESQT_1, FRONT.ESQT_11, NC1.2, NC2.2, NC3.2, NC4.2, NC5.2, NC6.2, NC7.2, NC8.2, NC9.2, NC10.2, NC11.2, NC12.2, NC13.2, NC14.2, NC15.2, NC16.2, NC17.2, NC18.2, NC19.2, NC20.2, NC21.2, NC22.-, NC23.-, NC24.2, NEO1.3-GND (GND), NEO2.3-GND (GND), NEO3.3-GND (GND), NEO4.3-GND (GND), NEO5.3-GND (GND), NEO6.3-GND (GND), NEO7.3-GND (GND), NEO8.3-GND (GND), NEO9.3-GND (GND), NEO10.3-GND (GND), NEO11.3-GND (GND), NEO12.3-GND (GND), NEO13.3-GND (GND), NEO14.3-GND (GND), NEO15.3-GND (GND), NEO16.3-GND (GND), NEO17.3-GND (GND), NEO18.3-GND (GND), NEO19.3-GND (GND), NEO20.3-GND (GND), REAR.ESQT_5, REAR.ESQT_6, S1.1, S1.2, S1.3, S1.4, S1.5, S1.6, S1.7, S1.8, S1.9, S1.10, U1.4 (VSS), U1.5 (VSS), U$1.P$7, U$2.P$2, U$3.GND, V_REG.GND
LRCLK: FRONT.ESQT_10, R10.2, REAR.ESQT_4
LRCLK88: R10.1, U$3.23/A9 (23/A9/T/PWM)
M0: R23.1, S1.20, U$3.14/A0 (14/A1)
M1: R22.1, S1.19, U$3.12 (12/MISO)
M2: R21.1, S1.18, U$3.11 (11/MOSI)
M3: R20.1, S1.17, U$3.10 (10/TX2/PWM)
M4: R19.1, S1.16, U$3.8 (8/TX3)
M5: R18.1, S1.15, U$3.7 (7/RX3)
M6: R17.1, S1.14, U$3.6 (6/PWM)
M7: R16.1, S1.13, U$3.4 (4/CAN-RX/PWM)
M8: R14.1, S1.12, U$3.3 (3/CAN-TX/PWM)
M9: R24.1, S1.11, U$3.2
MIC_DATA: FRONT.ESQT_9, REAR.ESQT_3, U$3.13 (13/SCK/LED)
unnamed: U$1.P$6, U$1.P$12
unnamed: U$1.P$1, V_REG.VIN
unnamed: NEO2.2-DOUT (DO), NEO3.4-DIN (DI)
unnamed: NEO5.2-DOUT (DO), NEO6.4-DIN (DI)
unnamed: NEO9.2-DOUT (DO), NEO10.4-DIN (DI)
unnamed: NEO11.2-DOUT (DO), NEO12.4-DIN (DI)
unnamed: NEO4.2-DOUT (DO), NEO5.4-DIN (DI)
unnamed: NEO15.2-DOUT (DO), NEO16.4-DIN (DI)
unnamed: NEO3.2-DOUT (DO), NEO4.4-DIN (DI)
unnamed: NEO7.2-DOUT (DO), NEO8.4-DIN (DI)
unnamed: NEO8.2-DOUT (DO), NEO9.4-DIN (DI)
unnamed: NEO18.2-DOUT (DO), NEO19.4-DIN (DI)
unnamed: NEO13.2-DOUT (DO), NEO14.4-DIN (DI)
unnamed: NEO16.2-DOUT (DO), NEO17.4-DIN (DI)
unnamed: NEO12.2-DOUT (DO), NEO13.4-DIN (DI)
unnamed: NEO19.2-DOUT (DO), NEO20.4-DIN (DI)
unnamed: NEO6.2-DOUT (DO), NEO7.4-DIN (DI)
unnamed: NEO17.2-DOUT (DO), NEO18.4-DIN (DI)
NEOLOOP: FRONT.ESQT_4, NEO11.4-DIN (DI)
NEO_P1: NEO1.2-DOUT (DO), NEO2.4-DIN (DI)
NEO_P2: NEO14.2-DOUT (DO), NEO15.4-DIN (DI)
NEO_P_CTRL: R13.2, U$3.5 (5/PWM)
NEO_P_CTRL_INT: NEO1.4-DIN (DI), R13.1
POT1: POT1.P$1, U$3.22/A8 (22/A8/T/PWM)
POT2: POT2.P$1, U$3.21/A7 (21/A7/PWM)
POT3: POT3.P$1, U$3.20/A6 (20/A6/PWM)
POT4: POT4.P$1, U$3.17/A3 (17/A3/T)
SCL: FRONT.ESQT_3, R2.2, REAR.ESQT_9, U1.2 (SCL), U$3.19/A5 (19/A5/T/SCL0)
SDA: FRONT.ESQT_8, R1.2, REAR.ESQT_2, U1.3 (SDA), U$3.18/A4 (18/A4/T/SDA0)
SHDN: U$2.P$1, U$3.15/A1 (15/A1/T), V_REG.EN

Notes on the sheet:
I2S MEMS Microphones
Voltage Regulator
I2C LUX Sensors
NeoPixel LEDs
One cap near each NeoPixel
Teensy 3.2
Designed by Nathan Villicana-Shaw Victoria University of Wellington School of Engineering and Computer Science
14/10/2019
DIP Configuration Switches
This cap needs to be close to the first neopixel
Add p-channel mosfet to protect the circuit from battery placed in the wrong direction.
Connections to the Breakout Boards
DOUBLE CHECK BCLK PIN NUMBER
TODO - add a 3pos 2.54 header for connecting the Neopixel front and back when no external PCBs are used

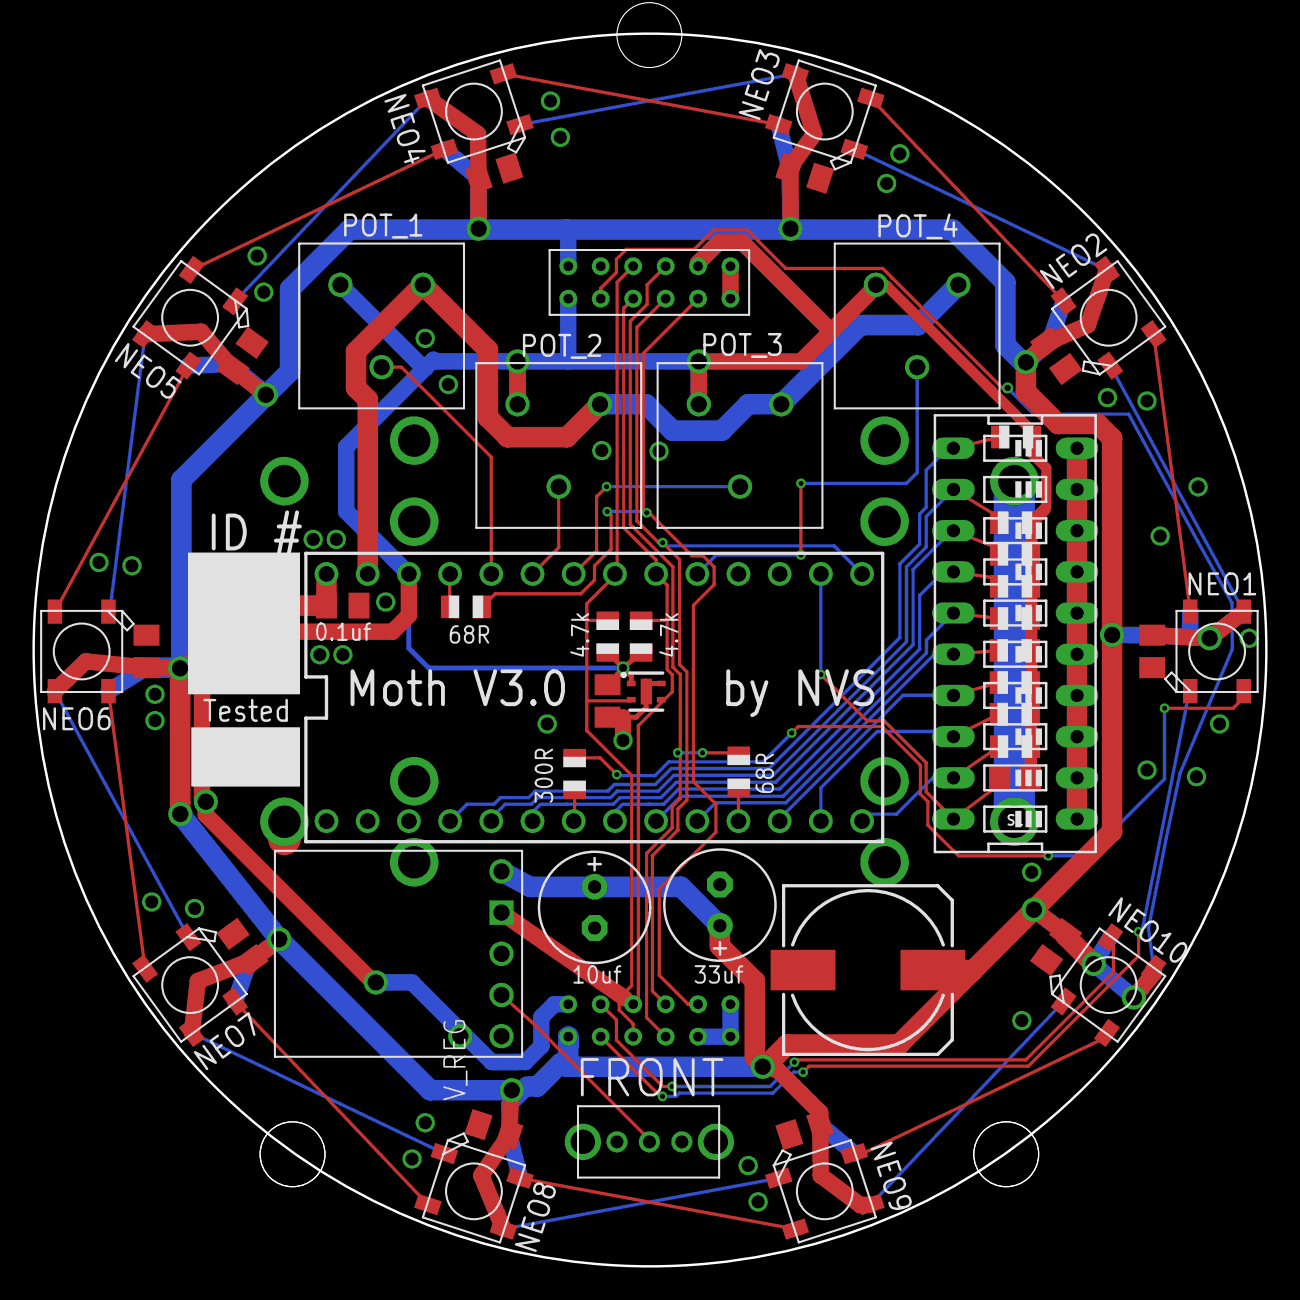
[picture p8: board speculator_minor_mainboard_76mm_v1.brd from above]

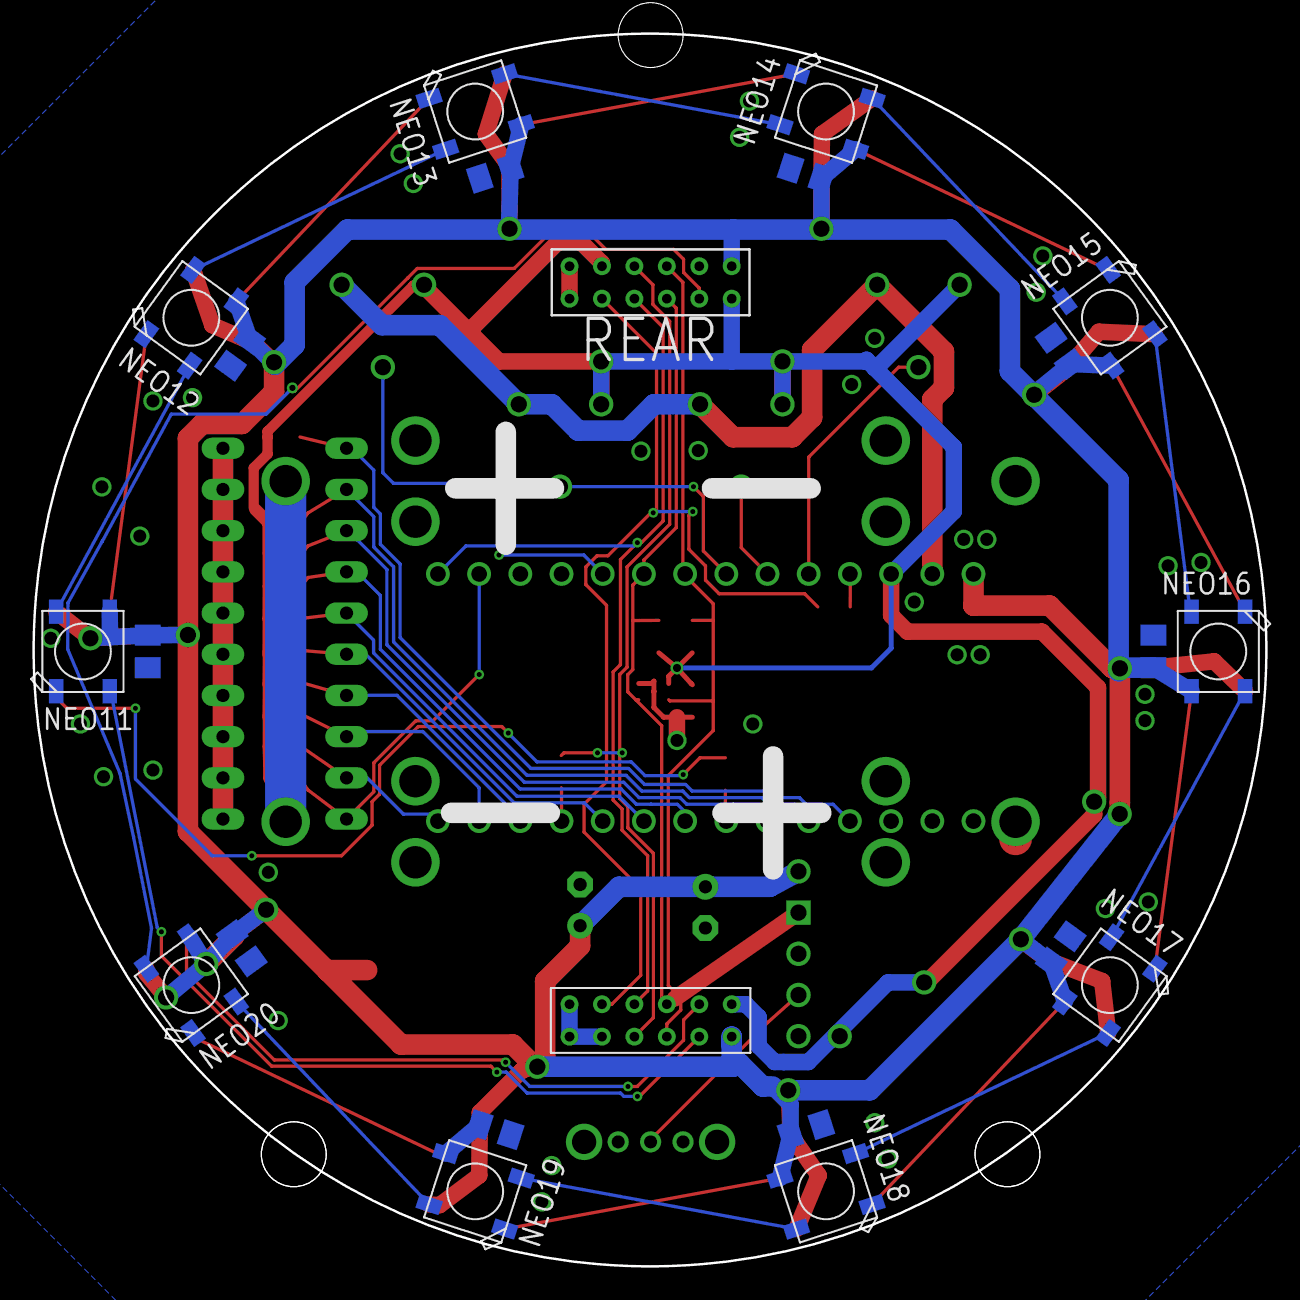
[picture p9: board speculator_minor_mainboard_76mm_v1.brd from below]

Board: 2 copper layers, 76.0 x 76.0 mm, 72 parts (22 on the bottom side), 51 nets.

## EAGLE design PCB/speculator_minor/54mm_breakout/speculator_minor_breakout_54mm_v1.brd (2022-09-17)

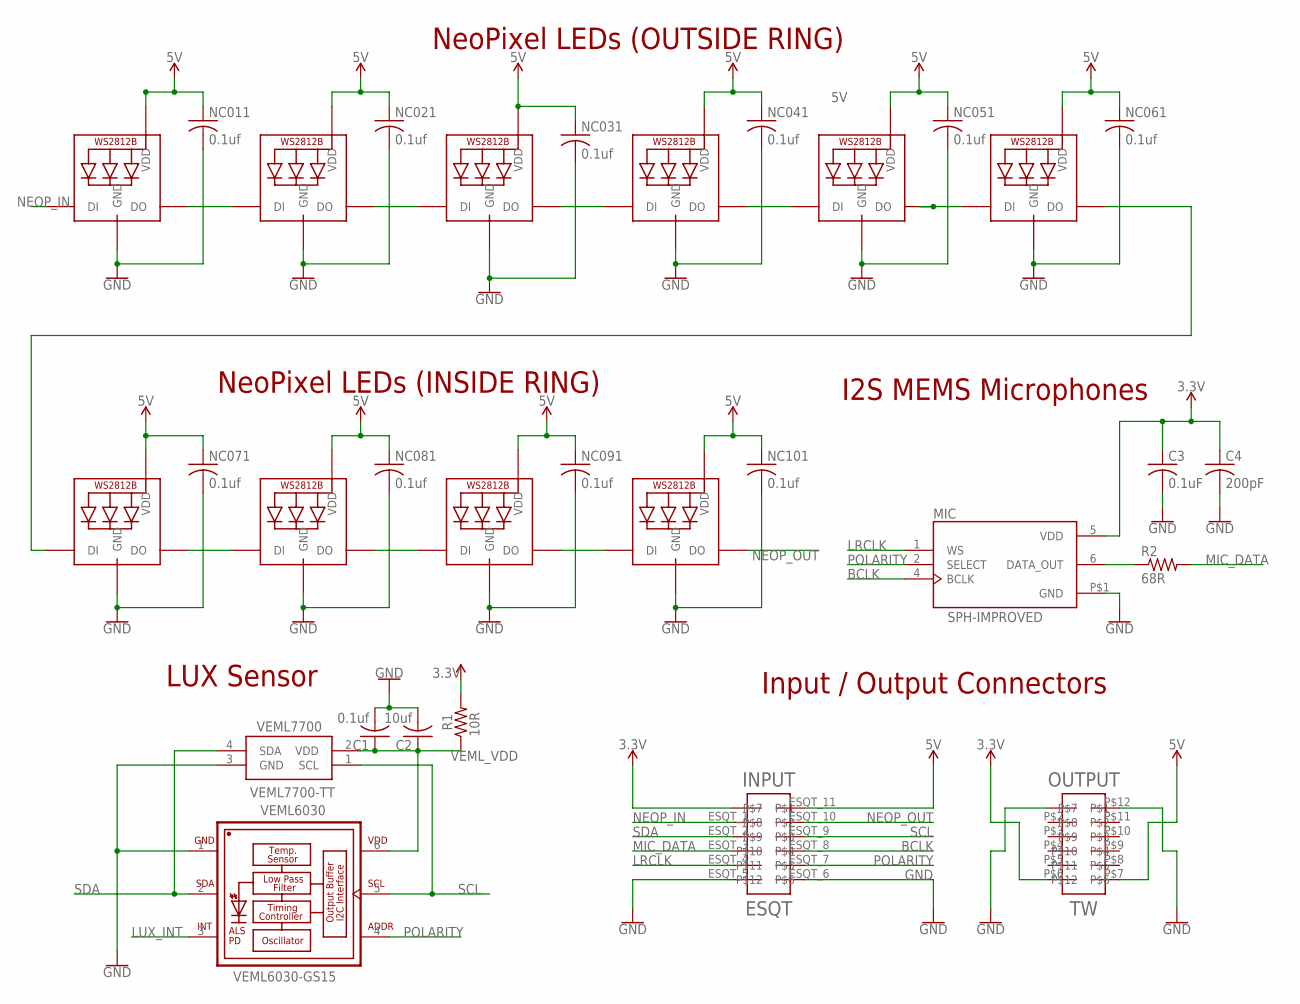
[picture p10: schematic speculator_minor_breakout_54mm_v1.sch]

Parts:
C1: 0.1uf; C0805
C2: 10uf; C0805
C3: 0.1uF; C0805
C4: 200pF; C0805
INPUT: ESQT; SAMTEC_ESQT_2X6_THROUGH_HOLE
MIC: SPH-IMPROVED; MIC_SPH0645LM4H-B_LARGER_RING
NC011, NC021, NC031, NC041, NC051, NC061, NC071, NC081, NC091, NC101: 0.1uf; C0805K
NEO1, NEO2, NEO3, NEO4, NEO5, NEO6, NEO07, NEO08, NEO9, NEO10: WS2812B5050; WS2812B
OUTPUT: TW; SAMTEC_TW_2X6
R1: 10R; R0805
R2: 68R; M0805
VEML6030: VEML6030-GS15; VISHAY_VEML6030_2X2X0.87
VEML7700: VEML7700-TT; VEML7700

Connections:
3.3V: C3.1, C4.1, INPUT.ESQT_0, MIC.5 (VDD), OUTPUT.P$6, R1.2
5V: INPUT.ESQT_11, NC011.1, NC021.1, NC031.1, NC041.1, NC051.1, NC061.1, NC071.1, NC081.1, NC091.1, NC101.1, NEO1.1-VDD (VDD), NEO2.1-VDD (VDD), NEO3.1-VDD (VDD), NEO4.1-VDD (VDD), NEO5.1-VDD (VDD), NEO6.1-VDD (VDD), NEO07.1-VDD (VDD), NEO08.1-VDD (VDD), NEO9.1-VDD (VDD), NEO10.1-VDD (VDD), OUTPUT.P$7
1232135: NEO08.2-DOUT (DO), NEO9.4-DIN (DI)
BCLK: INPUT.ESQT_8, MIC.4 (BCLK)
GND: C1.2, C2.2, C3.2, C4.2, INPUT.ESQT_5, INPUT.ESQT_6, MIC.P$1 (GND), NC011.2, NC021.2, NC031.2, NC041.2, NC051.2, NC061.2, NC071.2, NC081.2, NC091.2, NC101.2, NEO1.3-GND (GND), NEO2.3-GND (GND), NEO3.3-GND (GND), NEO4.3-GND (GND), NEO5.3-GND (GND), NEO6.3-GND (GND), NEO07.3-GND (GND), NEO08.3-GND (GND), NEO9.3-GND (GND), NEO10.3-GND (GND), OUTPUT.P$1, OUTPUT.P$12, VEML6030.1 (GND), VEML7700.3 (GND)
LRCLK: INPUT.ESQT_4, MIC.1 (WS)
LUX_INT: VEML6030.3 (INT)
MIC_DATA: INPUT.ESQT_3, R2.2
unnamed: NEO3.2-DOUT (DO), NEO4.4-DIN (DI)
unnamed: NEO4.2-DOUT (DO), NEO5.4-DIN (DI)
unnamed: NEO9.2-DOUT (DO), NEO10.4-DIN (DI)
unnamed: NEO07.2-DOUT (DO), NEO08.4-DIN (DI)
unnamed: NEO6.2-DOUT (DO), NEO07.4-DIN (DI)
unnamed: NEO5.2-DOUT (DO), NEO6.4-DIN (DI)
unnamed: NEO1.2-DOUT (DO), NEO2.4-DIN (DI)
unnamed: MIC.6 (DATA_OUT), R2.1
unnamed: NEO2.2-DOUT (DO), NEO3.4-DIN (DI)
NEOP_IN: INPUT.ESQT_1, NEO1.4-DIN (DI)
NEOP_OUT: INPUT.ESQT_10, NEO10.2-DOUT (DO)
POLARITY: INPUT.ESQT_7, MIC.2 (SELECT), VEML6030.4 (ADDR)
SCL: INPUT.ESQT_9, VEML6030.5 (SCL), VEML7700.1 (SCL)
SDA: INPUT.ESQT_2, VEML6030.2 (SDA), VEML7700.4 (SDA)
VEML_VDD: C1.1, C2.1, R1.1, VEML6030.6 (VDD), VEML7700.2 (VDD)

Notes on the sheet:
I2S MEMS Microphones
LUX Sensor
NeoPixel LEDs (OUTSIDE RING)
10R
NeoPixel LEDs (INSIDE RING)
Input / Output Connectors

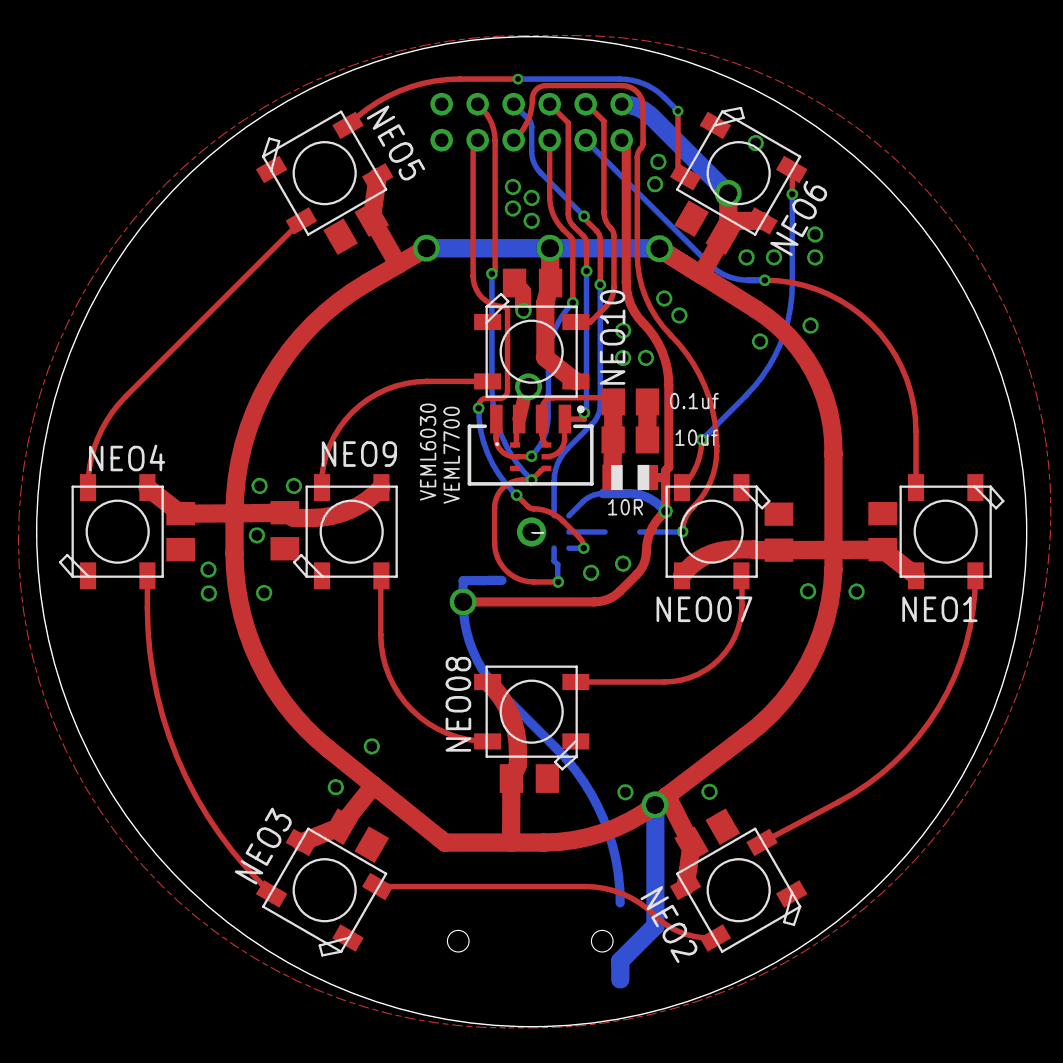
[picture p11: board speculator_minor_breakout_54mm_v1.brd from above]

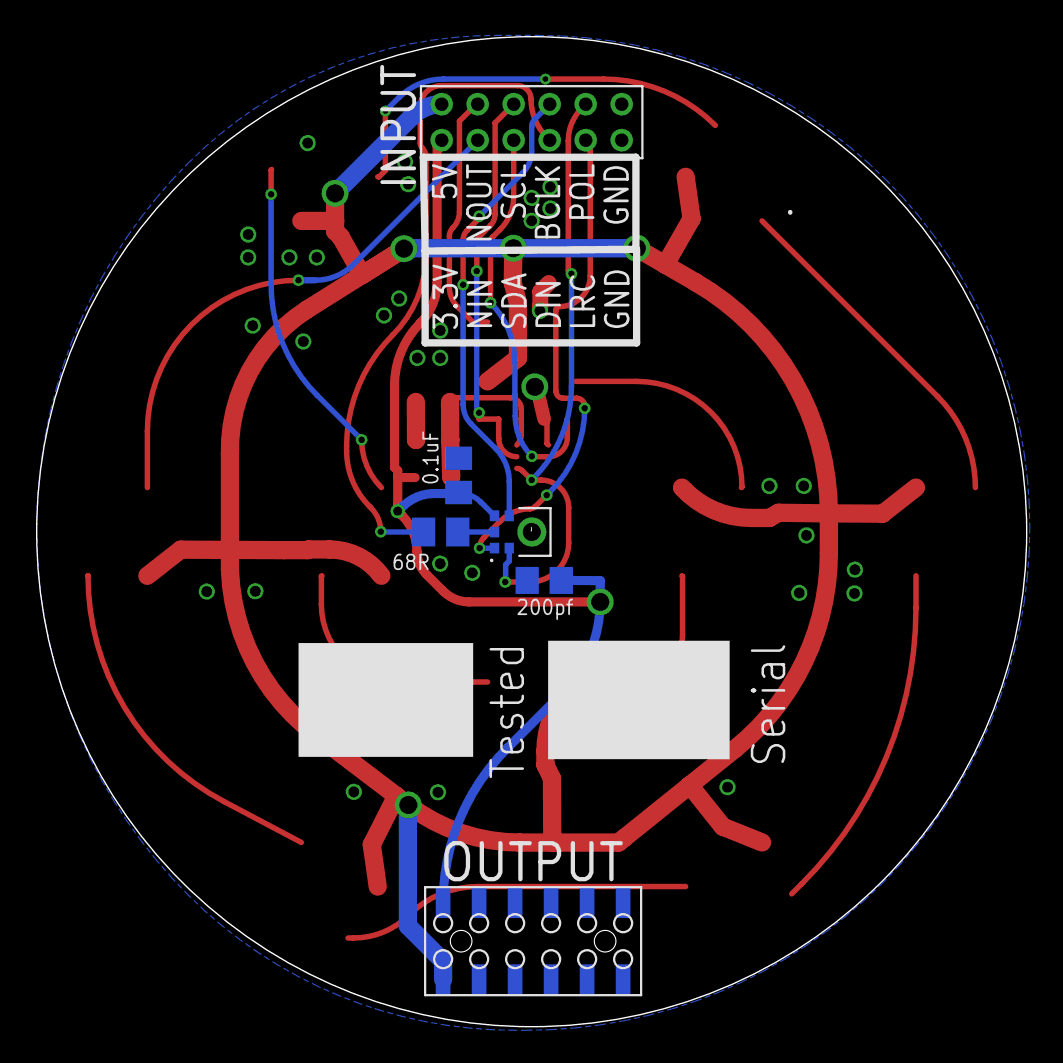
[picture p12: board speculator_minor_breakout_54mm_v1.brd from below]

Board: 2 copper layers, 55.0 x 55.0 mm, 31 parts (6 on the bottom side), 22 nets.

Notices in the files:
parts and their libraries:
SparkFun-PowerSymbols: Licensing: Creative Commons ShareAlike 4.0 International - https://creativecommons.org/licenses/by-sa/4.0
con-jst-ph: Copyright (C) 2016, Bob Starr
